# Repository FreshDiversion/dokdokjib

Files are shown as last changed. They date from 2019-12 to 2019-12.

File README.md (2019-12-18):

# dokdokjib
A DIY Home Automation System Using open source materials

The future is smart, the future is automated. The future belongs to the people.

Currently, as we are all aware, the majority of the innovations in technology that are available to the every-day individual are controlled by large corporations. The window through which the every-day person can conceive, develop, and produce their own technological innovations, on the scale of a full home automation system, is small.

This project concerned itself with the future of smart home automation(IOT), digital assistants(Siri, Google Home, Alexa), and the ever growing presence of voice recognition technologies(NLP). These concepts, and developing a user-friendly and accessible play that everyone can create and self educate in terms of developing their own technologies.

Our goal was to develop a system that was inexpensive and accessible to everyone. In addition, we found that many of our users would be individuals with little to no experience in technology. Our product had to be easy to install and customize for the user.

In keeping the cost to within an acceptable margin, we employed the concepts of up-cycling old technologies, creating within the boundaries of inexpensive microprocessors and microcomputers running open source software as well as basic code written by the team.

Exploring these concepts we examined the two sides of the home of the future. 
Automation: the sensing and collecting of data and Control: the user interface by which the resident home owner lives within a smart system.

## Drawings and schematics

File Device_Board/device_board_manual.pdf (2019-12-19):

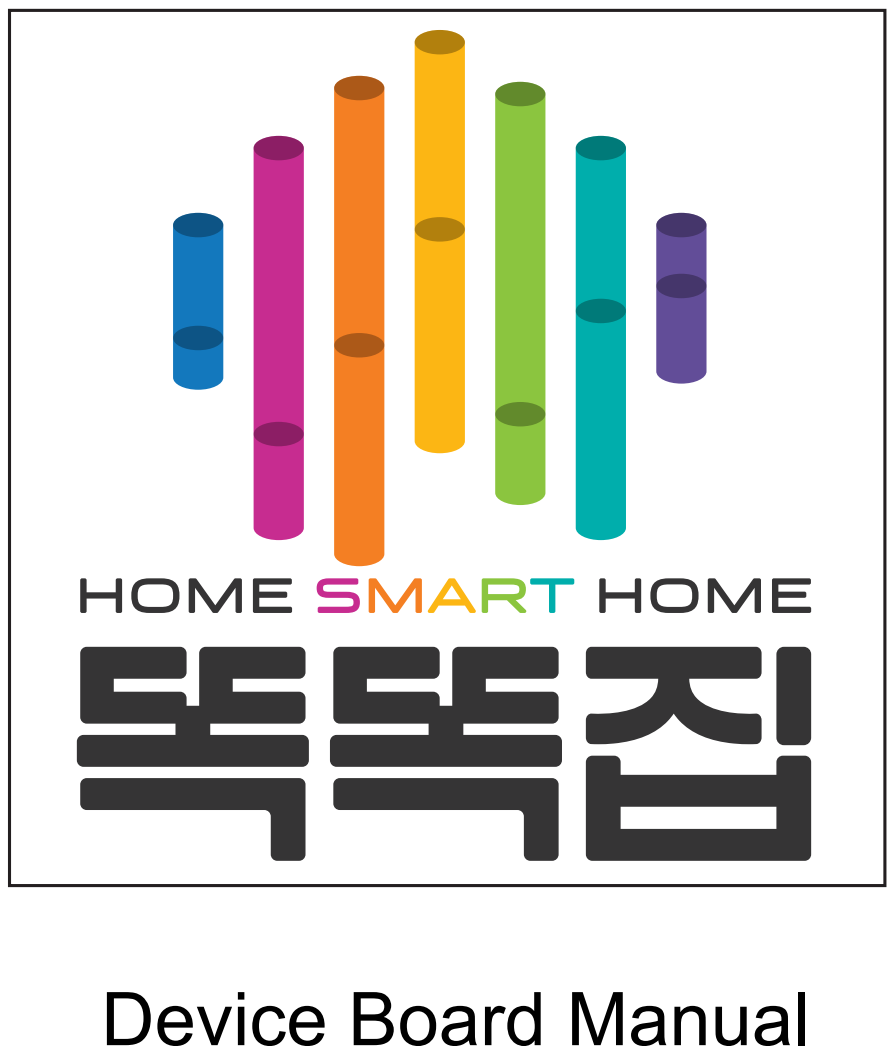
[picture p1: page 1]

Device Board Manual

22pf Capacitor
QTY: 2

LM317 Adjustable
Voltage Regulator
QTY: 1

POWER_JACK
QTY: 1

RED LED3MM
QTY: 1

GREENLED3MM
QTY: 1

16mhz Crystal
QTY: 1

10k Resistor
QTY: 1

330 ohm Resistor
QTY: 3

560 ohm Resistor
QTY: 1

1X4 Female Socket
QTY: 2

IC Socket DIP28
QTY: 1

Terminal Block 2 pos
QTY: 4

Terminal Block 3 pos
QTY: 4

1X10 2mm female
socket
QTY: 2

NS-LS2 Level Shifter
QTY: 1

# Device Board Parts

XBee S1 Radio
QTY: 1

# Device Board Diagram

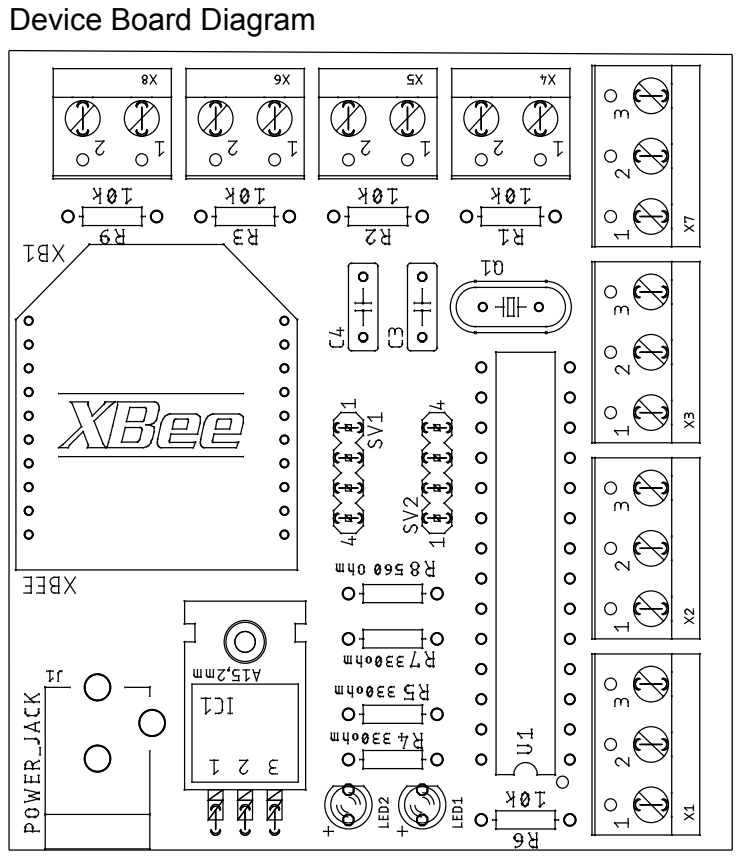
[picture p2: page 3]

Part | Value
C3 | 22pf Capacitor
C4 | 22pf Capacitor
IC1 | LM317MABT
J1 | POWER_JACK
LED1 | RED LED3MM - long leg in + hole
LED2 | Green LED3MM - long leg in + hole
Q1 | 16mhz Crystal
R1 | 10k Resistor (Brown, Black, Orange) Optional
R2 | 10k Resistor (Brown, Black, Orange) Optional
R3 | 10k Resistor (Brown, Black, Orange) Optional
R4 | 330ohm Resistor (Orange, Orange, Brown)
R5 | 330ohm Resistor (Orange, Orange, Brown)
R6 | 10k Resistor
R7 | 330ohm Resistor (Orange, Orange, Brown)
R8 | 560 Ohm Resistor (Green, Blue, Brown)
R9 | 10k Resistor (Brown, Black, Orange)
SV1 | 1X4 Female Socket - For the level shifter
SV2 | 1X4 Female Socket - For the level shifter
U1 | IC Socket DIP28
X1 | Terminal Block 3 pos
X2 | Terminal Block 3 pos
X3 | Terminal Block 3 pos
X4 | Terminal Block 2 pos
X5 | Terminal Block 2 pos
X6 | Terminal Block 2 pos
X7 | Terminal Block 3 pos
X8 | Terminal Block 2 pos

# Device Board Partlist

These parts have a letter/number destignation. Match the designation in the list with the corresponding designation on the board diagram.

Pay attention to the orientation of the components. Some need to be soldered/inserted in the proper orientation.

R1 R2 and R3 are optional. Only if a switch is connected are they necessary.

# Device Board Notes

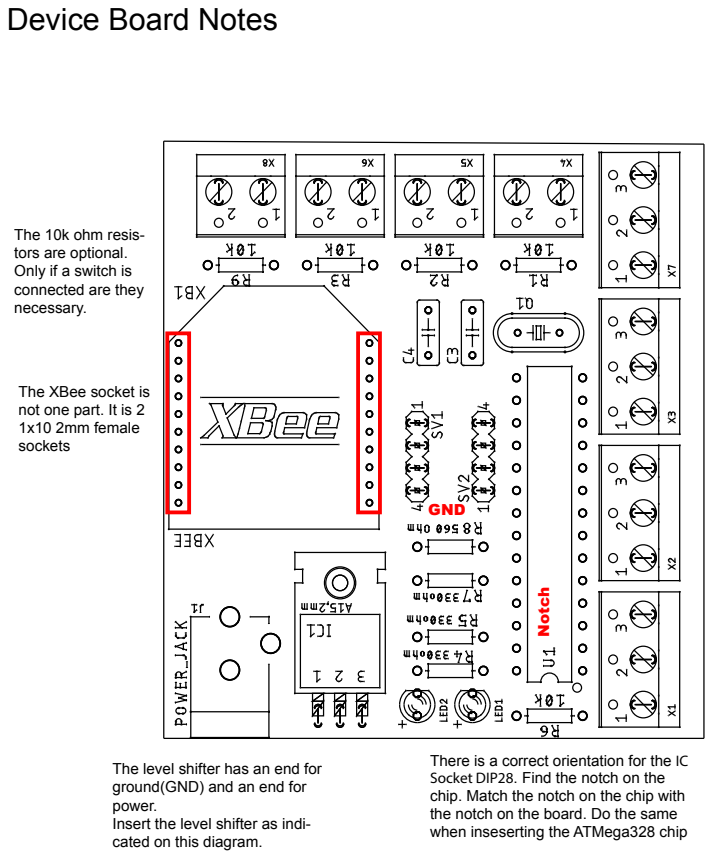
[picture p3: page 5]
GND; Notch

The 10k ohm resis-
tors are optional.
Only if a switch is
connected are they
necessary.

The XBee socket is
not one part. It is 2
1x10 2mm female
sockets

The level shifter has an end for
ground(GND) and an end for
power.
Insert the level shifter as indi-
cated on this diagram.

There is a correct orientation for the IC
Socket DIP28. Find the notch on the
chip. Match the notch on the chip with
the notch on the board. Do the same
when inseserting the ATMega328 chip

# Completed Device Board

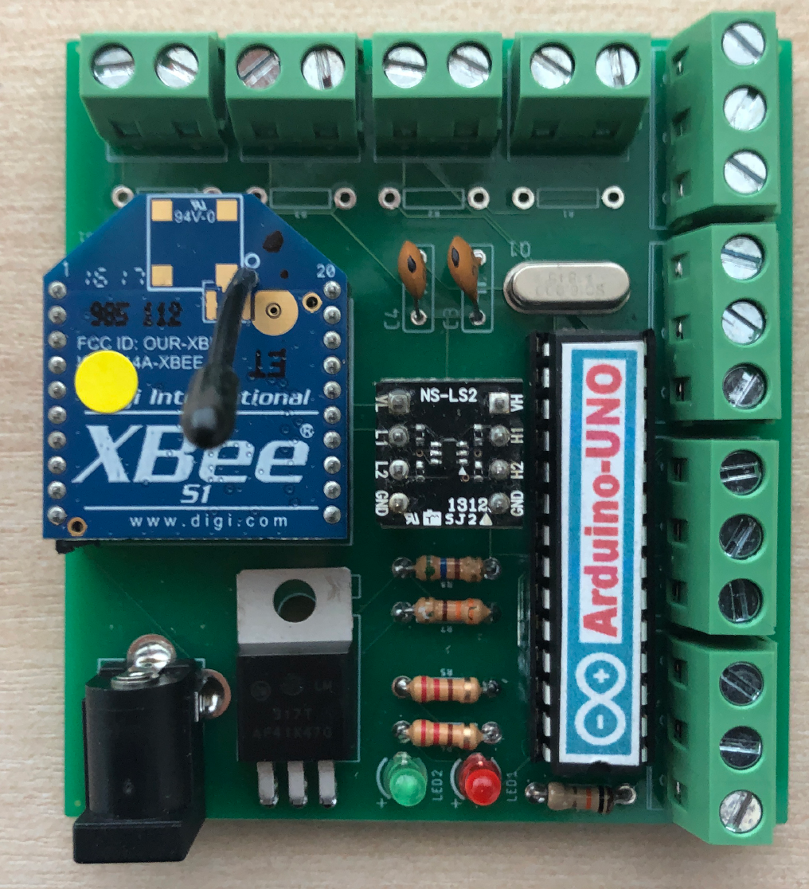
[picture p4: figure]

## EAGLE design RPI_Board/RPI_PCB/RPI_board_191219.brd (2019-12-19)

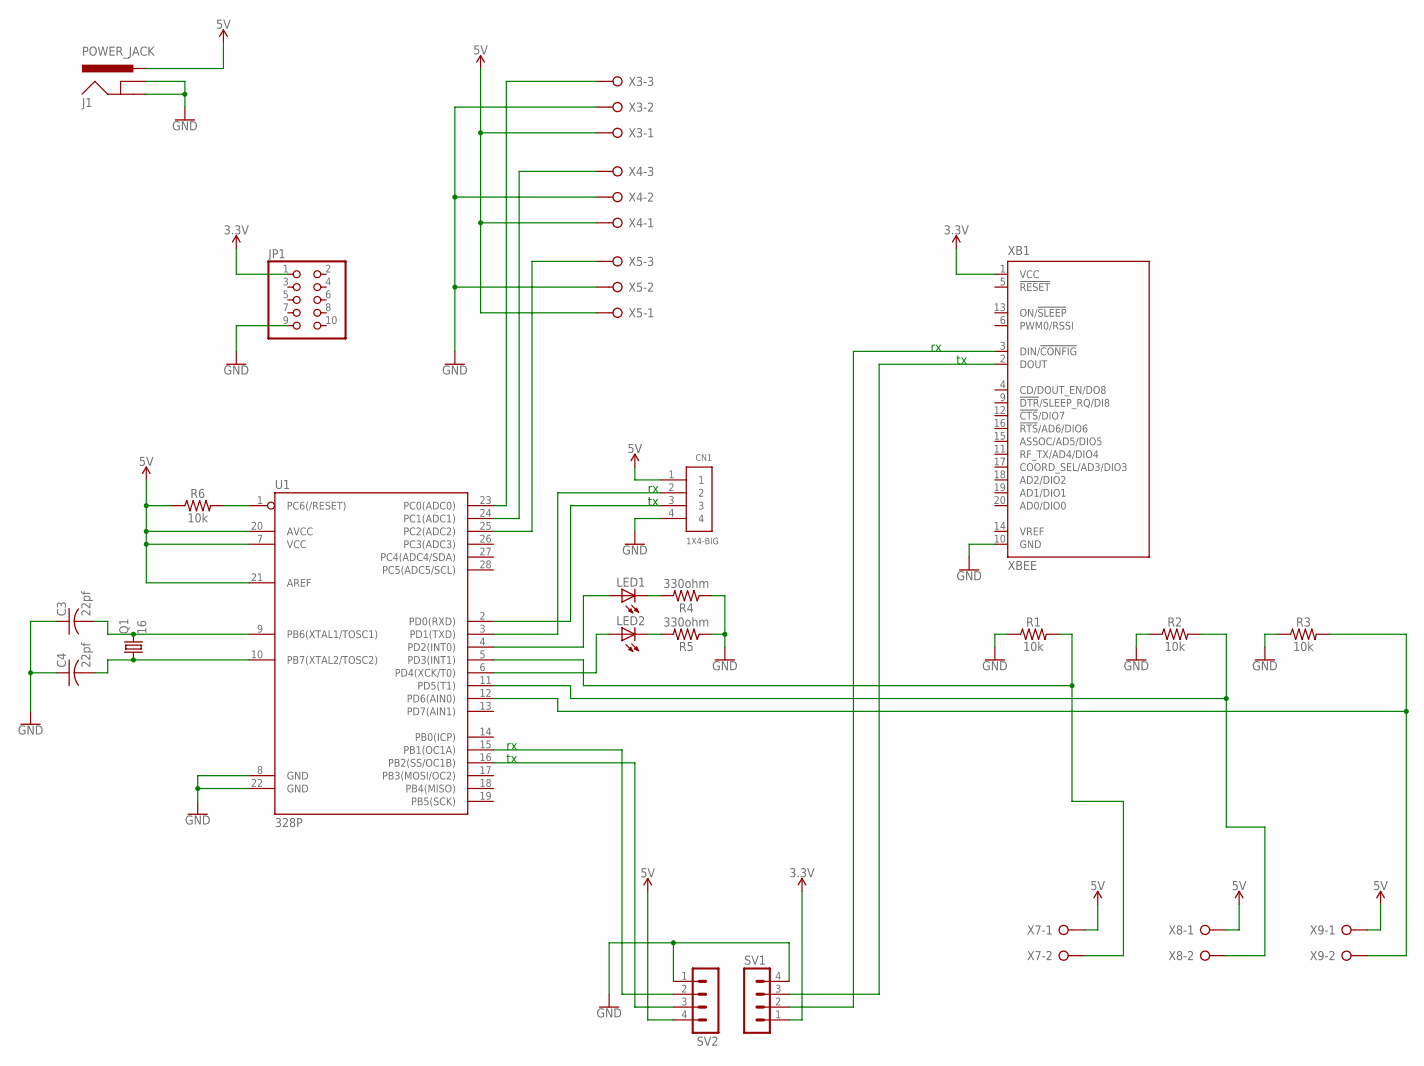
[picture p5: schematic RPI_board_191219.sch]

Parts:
C3, C4: 22pf; C050-025X075
CN1: 1X4-BIG; 1X04-BIG
J1: POWER_JACK; POWER_JACK_PTH
JP1: PINHD-2X5; 2X05
LED1, LED2: LED3MM
Q1: 16; HC49/S
R1, R2, R3, R6: 10k; AXIAL-0.3
R4, R5: 330ohm; AXIAL-0.3
SV1, SV2: MA04-1
U1: 328P; DIP28
X3, X4, X5: W237-3E
X7, X8, X9: W237-02P; W237-132
XB1: XBEE

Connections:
3.3V: JP1.1, SV1.1, XB1.1 (VCC)
5V: CN1.1, J1.PWR, R6.P$1 (1), SV2.4, U1.7 (VCC), U1.20 (AVCC), U1.21 (AREF), X3.1, X4.1, X5.1, X7.1, X8.1, X9.1
GND: C3.1, C4.1, CN1.4, J1.GND, J1.GNDBREAK, JP1.9, R1.P$1 (1), R2.P$1 (1), R3.P$1 (1), R4.P$1 (1), R5.P$1 (1), SV1.4, SV2.1, U1.8 (GND), U1.22 (GND), X3.2, X4.2, X5.2, XB1.10 (GND)
unnamed: CN1.3, U1.2 (PD0(RXD))
unnamed: CN1.2, U1.3 (PD1(TXD))
unnamed: U1.23 (PC0(ADC0)), X3.3
unnamed: U1.24 (PC1(ADC1)), X4.3
unnamed: U1.25 (PC2(ADC2)), X5.3
unnamed: LED1.A, U1.4 (PD2(INT0))
unnamed: LED2.A, U1.6 (PD4(XCK/T0))
unnamed: R1.P$2 (2), U1.5 (PD3(INT1)), X7.2
unnamed: LED2.K (C), R5.P$2 (2)
unnamed: LED1.K (C), R4.P$2 (2)
unnamed: C3.2, Q1.2, U1.9 (PB6(XTAL1/TOSC1))
unnamed: C4.2, Q1.1, U1.10 (PB7(XTAL2/TOSC2))
unnamed: R6.P$2 (2), U1.1 (PC6(/RESET))
unnamed: R3.P$2 (2), U1.12 (PD6(AIN0)), X9.2
unnamed: R2.P$2 (2), U1.11 (PD5(T1)), X8.2
unnamed: SV2.3, U1.16 (PB2(SS/OC1B))
unnamed: SV2.2, U1.15 (PB1(OC1A))
unnamed: SV1.2, XB1.3 (DIN/!CONFIG)
unnamed: SV1.3, XB1.2 (DOUT)

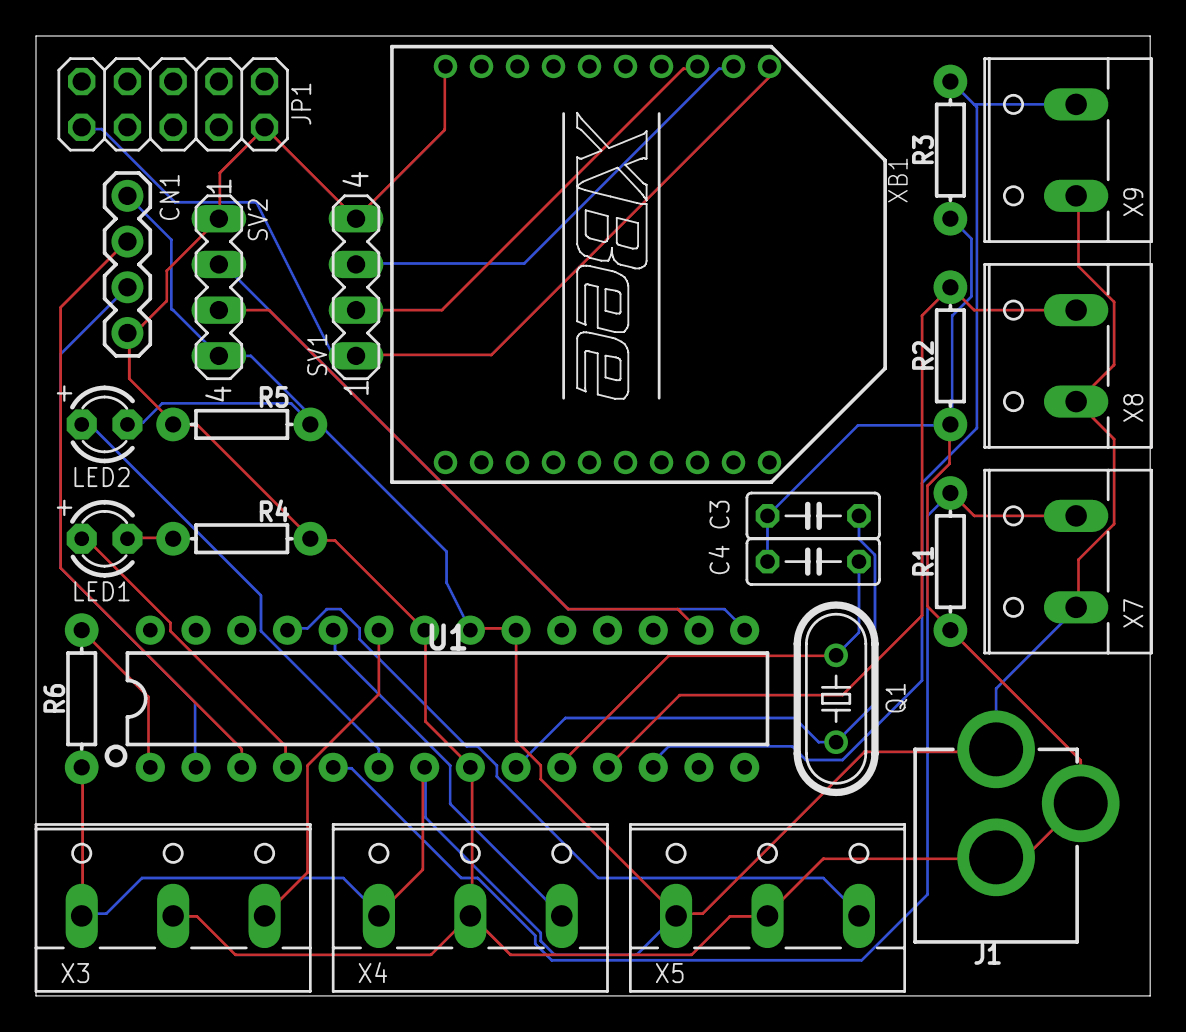
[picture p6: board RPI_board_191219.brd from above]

Board: 2 copper layers, 61.9 x 53.3 mm, 24 parts (0 on the bottom side), 22 nets.

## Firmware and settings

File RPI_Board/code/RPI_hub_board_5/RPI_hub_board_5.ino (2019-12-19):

//incluse the software serial library
#include <SoftwareSerial.h>

// Definitions
//xbee software serial pins software
#define xbee_rxPin 9
#define xbee_txPin 10

//declare software serial for the xbee
SoftwareSerial xbee_Serial(xbee_rxPin, xbee_txPin);

//declare a constant variable for the communication speed
const int theBaud = 9600;

//declare the strings for incomming data and set them to empty
String xbee_inString = "";
String hub_inString = "";

//*****************
//Pin assignments
//DO NOT CHANGE
//these are your INPUT/OUTPUT pins
//there are 6 I/O pins all together

//DIGITAL INPUT/OUTPUT
//3,6,7 have pwm
int io_1 = 3;
int io_2 = 6;
int io_3 = 7;

//ANALOG INPUT (and can be digital I/O)
int io_5 = A0;
int io_6 = A1;
int io_7 = A2;

//*****************

//DO NOT CHANGE
//LED Variables
int led0 = 2;
int led1 = 4;

int blinks;
int blinkDelay = 100;

// the setup routine runs once
void setup() {

  //set the pinmode of the LED
  pinMode(led0, OUTPUT);
  pinMode(led1, OUTPUT);

  //start usb/hub serial
  Serial.begin(theBaud);

  //start the xbee software serial
  xbee_Serial.begin(theBaud);

  //hub_Serial.println("SoftWareSerial Connected");
  Serial.println("Running_HUB_RXTX_5");

  //blink LED on startup
  blink_start(3);

}


// the loop routine runs over and over forever:
void loop() {

  //listen to the xbee radio
  xbee_listening();

  //listen to the hub
  hub_listening();

}

void xbee_listening()
{

  //Serial.println("xbee");

  //listen to the xbee for information
  while (xbee_Serial.available() > 0)
  {
    //Serial.println("xbee");
    //put incomming data into the inData variable
    char xbee_inData = xbee_Serial.read();

    xbee_inString += xbee_inData;

    if (xbee_inData == '\n') {

      //send the value to the hub
      Serial.println(xbee_inString);

      //clear the string for new input:
      xbee_inString = "";

      //blink the led once
      xbeeBlink(1);
      break;
    }

  }

}

void hub_listening()
{

  //xbee_Serial.print("1");
  //xbee_Serial.println("in");
 
  //listen to the hub for information
  while (Serial.available() > 0)
  {

    //put incomming data into the inData variable
    char hub_inData = Serial.read();

    //add the data to the incomming string
    hub_inString += hub_inData;

    if (hub_inData == '\n') {
      //send the data to the serial monitor
      //Serial.println(hub_inString);

      //send the value to the appropriate xbee
      xbee_Serial.println(hub_inString);
      //      xbee_Serial.print("1");
      //      xbee_Serial.println("in");

      // clear the string for new input:
      hub_inString = "";

      //bink the led once
      rpiBlink(1);
      break;
    }

  }

}


//these functions blink the LEDs
//blinks for sent data
void xbeeBlink(int blinks)
{

  for (int i = 0; i < blinks; i++)
  {

    digitalWrite(led1, HIGH);
    delay(blinkDelay);
    digitalWrite(led1, LOW);
    delay(blinkDelay);

  }

}

//blinks for data received
void rpiBlink(int blinks)
{

  for (int i = 0; i < blinks; i++)
  {

    digitalWrite(led0, HIGH);
    delay(blinkDelay);
    digitalWrite(led0, LOW);
    delay(blinkDelay);

  }

}

//blinks for startup
void blink_start(int blinks)
{

  for (int i = 0; i < blinks; i++)
  {

    digitalWrite(led0, HIGH);
    delay(blinkDelay);
    digitalWrite(led0, LOW);
    digitalWrite(led1, HIGH);
    delay(blinkDelay);
    digitalWrite(led1, LOW);

  }

}

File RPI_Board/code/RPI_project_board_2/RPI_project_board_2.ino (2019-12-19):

//incluse the software serial library
#include <SoftwareSerial.h>

//if your project uses libraries, add them here




// Definitions
//xbee software serial pins software
//DO NOT CHANGE
#define xbee_rxPin 9
#define xbee_txPin 10

//declare software serial object for the xbee
SoftwareSerial xbee_Serial(xbee_rxPin, xbee_txPin);

//declare a constant variable for the communication speed
const int theBaud = 9600;

//declare the strings for incomming data and set them to empty
String xbee_inString = "";
String rpi_inString = "";

//*****************


//this is your project ID number
char myID_Num = '1';


//*****************
//Pin assignments
//DO NOT CHANGE
//these are your INPUT/OUTPUT pins
//there are 6 I/O pins all together

//DIGITAL INPUT/OUTPUT
//3,6,7 have pwm
int io_1 = 3;
int io_2 = 5;
int io_3 = 6;



//ANALOG INPUT (and can be digital I/O)
int io_5 = A0;
int io_6 = A1;
int io_7 = A2;


//*****************

//declare your global variables here
//these variable are for your sensor data
//example:
int MY_GLOBAL_VARIABLE_0;

//more variables can be added
//int MY_GLOBAL_VARIABLE_1;


//*****************

//DO NOT CHANGE
//LED Variables
int led0 = 2;
int led1 = 4;

int blinks;
int blinkDelay = 100;

//*****************



// the setup routine runs once
void setup()
{

  //If you are using the Digital Input/Output pins,
  //set the PINMODE here.
  //preset pinmode commands
  //uncomment the pins you are using and change the MODE to INPUT or OUTPUT
  //pinMode(io_1, MODE);
  //pinMode(io_2, MODE);
  //pinMode(io_3, MODE);


  //DO NOT CHANGE
  //set the pinmode of the LED
  pinMode(led0, OUTPUT);
  pinMode(led1, OUTPUT);

  //start the xbee software serial
  xbee_Serial.begin(theBaud);

  //start usb/rpi serial
  Serial.begin(theBaud);

  //print a simple test message
  Serial.println("Running_RPI_PROJECT_RXTX_2");

  //blink LED on startup
  blink_start(3);

}


// the loop routine runs over and over forever:
void loop()
{

  //read the sensors
  readSensors();

  //listen to the xbee radio
  xbee_listening();

  //listen to the rpi
  //if your project does not require data from the hub, comment this out
  rpi_listening();

}


//This function reads your buttons and sensors
void readSensors()
{
  //DO YOUR SENSOR READING HERE
  //MAKE SURE YOUR DATA IS DECLARED IN A GLOBAL VARIABLE ABOVE
  //example:
  //MY_GLOBAL_VARIABLE = analogRead(io_5);

  //test variable
  MY_GLOBAL_VARIABLE_0 = random(0, 20);

  //this is for testing on the arduino board
  //  Serial.print("MY_GLOBAL_VARIABLE = ");
  //  Serial.println(MY_GLOBAL_VARIABLE_0);


  //do something with the data
  //uncomment if you are using sensor data
  //doSomething(MY_GLOBAL_VARIABLE_0);

}


//listen for incomming data from the xbee
//if the project is NOT receiving data from the hub, ignore this
void xbee_listening()
{

  //Serial.println("xbee");

  //listen to the xbee for information
  while (xbee_Serial.available() > 0)
  {
    //Serial.println("xbee");
    //put incomming data into the inData variable
    char xbee_inData = xbee_Serial.read();

    xbee_inString += xbee_inData;

    if (xbee_inData == '\n') {

      //send the value to the rpi
      Serial.println(xbee_inString);

      //OR

      //do something with the data
      //uncomment if you are using xbee data
      //doSomething(xbee_inString);

      //clear the string for new input:
      xbee_inString = "";

      //blink the led once
      xbeeBlink(1);
      break;
    }

  }

}


//listen for incomming data from the rpi
//if the project is NOT receiving data from the rpi, ignore this
void rpi_listening()
{

  //listen to the rpi for information
  while (Serial.available() > 0)
  {

    //put incomming data into the inData variable
    char rpi_inData = Serial.read();

    //add the data to the incomming string
    rpi_inString += rpi_inData;

    if (rpi_inData == '\n') {
      //this is for testing on the arduino board
      //Serial.println(rpi_inString);

      //If your project sends data to the hub, send it here
      //don't change
      xbee_Serial.print(myID_Num);
      xbee_Serial.print("_");

      //send the value to the hub
      xbee_Serial.println(rpi_inString);

      //OR*********

      //do something with the data
      //uncomment if you are using RPI data
      //doSomething(rpi_inString);


      // clear the string for new input:
      rpi_inString = "";

      //bink the led once
      rpiBlink(1);
      break;
    }

  }

}


//*****************


//this is where you do something with the data


//comment/uncomment the line that fits your data source
//if your data is coming from rpi_listening() or xbee_listening()
//void doSomething(string theData)

//if your data is coming from readSensors()
void doSomething(int theData)
{
  //this is for testing on the arduino board
  //Serial.print("My Data is: ");
  //Serial.println(theData);

  //example:
  //  if (theData <= 100)
  //  {
  //
  //    //turn the motor
  //
  //  }

}


//these functions blink the LEDs
//blinks for sent data
//green led
void xbeeBlink(int blinks)
{

  for (int i = 0; i < blinks; i++)
  {

    digitalWrite(led1, HIGH);
    delay(blinkDelay);
    digitalWrite(led1, LOW);
    delay(blinkDelay);

  }

}

//blinks for data received
//red led
void rpiBlink(int blinks)
{

  for (int i = 0; i < blinks; i++)
  {

    digitalWrite(led0, HIGH);
    delay(blinkDelay);
    digitalWrite(led0, LOW);
    delay(blinkDelay);

  }

}

//blinks for startup
void blink_start(int blinks)
{

  for (int i = 0; i < blinks; i++)
  {

    digitalWrite(led0, HIGH);
    delay(blinkDelay);
    digitalWrite(led0, LOW);
    digitalWrite(led1, HIGH);
    delay(blinkDelay);
    digitalWrite(led1, LOW);

  }

}

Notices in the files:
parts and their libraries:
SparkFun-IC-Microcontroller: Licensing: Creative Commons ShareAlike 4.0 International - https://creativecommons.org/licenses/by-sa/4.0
